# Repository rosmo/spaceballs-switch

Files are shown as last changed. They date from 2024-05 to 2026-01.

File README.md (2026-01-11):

# Spaceballs - The Switch!

Convert the [Concord Aerospace](https://www.concordaerospace.com/)'s 
[Ludicrous Speed Panel](https://www.concordaerospace.com/products/ludicrous-speed-control-panel) 
into a 5 switch Zigbee on/off switch. Only tested with Home Assistant. Switches 1-4 will be turned
on when the potentiometer is rotated (you may need to input your own calibration values though),
eg. plaid will have switched 1-4 in ON state. GO switch is switch number 5 and operates independently.

Requires ESP32-C6 and ESP-IDF 5.2. Tested with WeAct Studio ESP32-C6-MINI.

## Connecting hardware

Connect POT 1 to 3.3 VCC, POT 2 to pin 5, POT 3 to GND. Connect GO button to GND
and pin 20. Additional switch goes to pin 21 (and GND). Optional reset switch is at pin 17.

If you want to change the behavior so switches 1-4 are toggled independently, uncomment
`#define INDEPENDENT_SWITCHES`.

## Resetting device

Jumper 3V3 to pin 23 and reset the device.

## Building and flashing

Plug in your ESP32C6 to your computer (press BOOT, hold it and press RESET, then release BOOT) and replace `com4` with the
COM port the device appears on your computer.

1. `idf.py -p com4 erase-flash` 
2. `idf.py menuconfig`
3. `idf.py -p com4 flash`
4. Get the MAC address from console (the other port for ESP32-C6)
5. Create a manufacturing partition using [Zigbee Manufacturing Partition Generator Utility](https://github.com/espressif/esp-zigbee-sdk/blob/main/tools/mfg_tool/README.md).
6. Clone the zigbee sdk repo and remove the `from future.moves.itertools import zip_longest` from `tools/esp_zb_mfg_tool.py`.
7. Install dependencies in ESP-IDF shell: `python3 -m pip install -r requirements.txt` and `python3 -m pip install cryptography esp-idf-nvs-partition-gen crcmod`
8. Generate an installcode with Python: `python3 -c "import os;import crcmod.predefined;installcode=os.urandom(12);crc=crcmod.predefined.mkCrcFun('crc-16');print(installcode.hex() + hex(crc(installcode))[2:]);"`
9. Install dependencies for mgf tool: `python -m pip install esp_idf_nvs_partition_gen future`
10. Run: `python3 esp_zb_mfg_tool.py -i 7f91fbafb9ec53ee8097b3bb8fce -m 404ccafffe5627c4 -c 0x8000 -mn Espressif -mc 0x1338` (change first parameter to random string from previous command, second is MAC without colons)
11. Flash the binary to the `zb_fct` partition (at `0xf5000`): `esptool.py -p com4 write_flash 0xf5000 404ccafffe5627c4.bin`

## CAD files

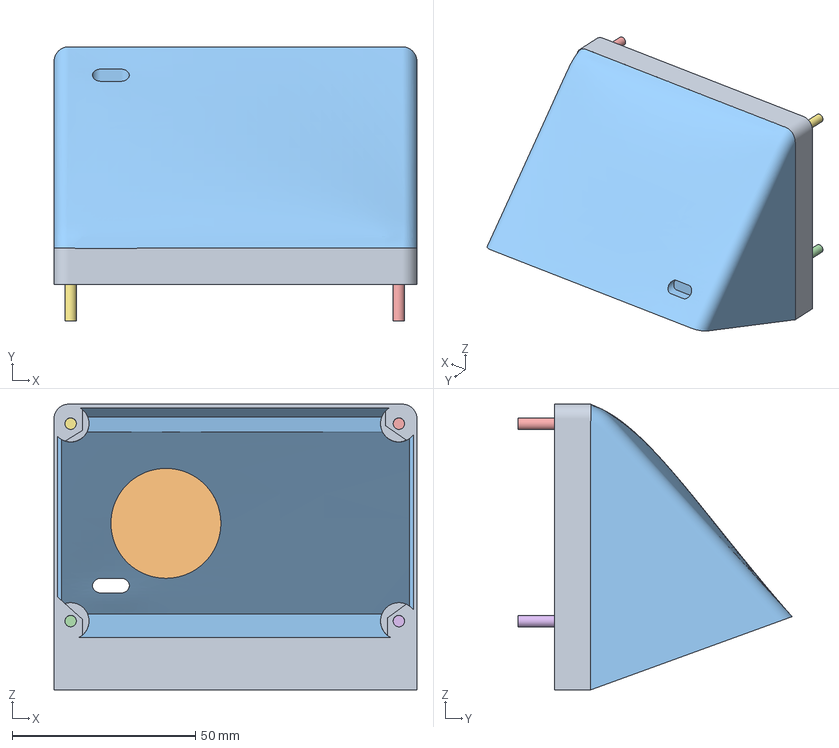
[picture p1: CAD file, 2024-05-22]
Spaceballs v6.3mf
99.1 x 74.9 x 78.0 mm
Front_plate
Pole
Wedge

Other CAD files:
Spaceballs v6.stl

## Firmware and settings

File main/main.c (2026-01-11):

#include "esp_check.h"
#include "esp_err.h"
#include "string.h"
#include "nvs_flash.h"
#include "esp_log.h"
#include "freertos/FreeRTOS.h"
#include "freertos/task.h"
#include "ha/esp_zigbee_ha_standard.h"
#include "main.h"
#include "esp_ieee802154.h"
#include "esp_mac.h"
#include "esp_adc/adc_oneshot.h"
#include "driver/gpio.h"

static const char *TAG = "ESP_ZB_SPACEBALLS";

// Spaceballs - The Switch!
static char modelid[] = {24, 'S', 'p', 'a', 'c', 'e', 'b', 'a', 'l', 'l', 's', ' ', '-', ' ', 'T', 'h', 'e', ' ', 'S', 'w', 'i', 't', 'c', 'h', '!'};
static char manufname[] = {9, 'E', 's', 'p', 'r', 'e', 's', 's', 'i', 'f'};

#if CONFIG_SPACEBALLS_BUTTON_PULLUP
#define BUTTON_PRESSED 0
#else
#define BUTTON_PRESSED 1
#endif

#define BUTTON_DEBUG 1
#define ADC_DEBUG 1

#define RESET_GPIO_PIN CONFIG_SPACEBALLS_RESET_GPIO

#define SB_ADC_CHANNEL CONFIG_SPACEBALLS_POTENTIOMETER_ADC_CHANNEL
#define SB_ADC_ATTEN   ADC_ATTEN_DB_12

#if SPACEBALLS_INDEPENDENT_SWITCHES
#define INDEPENDENT_SWITCHES 
#endif

#define BUTTON_1        (1<<0) // Light
#define BUTTON_2        (1<<1) // Ridiculous
#define BUTTON_3        (1<<2) // Ludicrous
#define BUTTON_4        (1<<3) // Plaid
#define BUTTON_5        (1<<4) // Go
#define BUTTON_6        (1<<5) // Additional switch
#define BUTTON_GPIO_5   CONFIG_SPACEBALLS_GO_GPIO     // Go button GPIO

trigger_range trigger_ranges[] = {
    {
        //.min = 2600,
        //.max = 3200,
        .min = 400,
        .max = 800,
        .button = BUTTON_1, // Light
        .name = "Light",
    },
    {
        //.min = 2100,
        //.max = 2599,
        .min = 800,
        .max = 1200,
        .button = BUTTON_2, // Ridiculous
        .name = "Ridiculous",
    },
    {
        //.min = 1200,
        //.max = 2099,
        .min = 1000,
        .max = 1700, 
        .button = BUTTON_3, // Ludicrous
        .name = "Ludicrous",
    },
    {
        //.min = 0,
        //.max = 1199,
        .min = 1500,
        .max = 4095,
        .button = BUTTON_4, // Plaid
        .name = "Plaid",
    },
};

#if CONFIG_SPACEBALLS_ADDITIONAL_SWITCH
#define TOTAL_BUTTONS           ((sizeof(trigger_ranges) / sizeof(trigger_range)) + 2)
#define GO_BUTTON_NUM           TOTAL_BUTTONS - 2
#define ADDITIONAL_BUTTON_NUM   TOTAL_BUTTONS - 1
#else
#define TOTAL_BUTTONS   ((sizeof(trigger_ranges) / sizeof(trigger_range)) + 1)
#define GO_BUTTON_NUM           TOTAL_BUTTONS - 1
#endif

// Internal button state
static uint8_t button_state = 0, previous_state = 0;
static uint8_t button_attrs[TOTAL_BUTTONS];
static uint8_t button_attrs_previous[TOTAL_BUTTONS];
static bool zigbee_initialized = false;

static nvs_handle_t nvs;
static float_t adc_reading = 0;

static SemaphoreHandle_t update_sem;

esp_err_t load_min_max_values(nvs_handle_t handle) 
{
    char key[32] = { '\0' };
    esp_err_t err;
    int16_t val;

    for (int i = 0; i < TOTAL_BUTTONS; i++) {
        // min value
        snprintf(key, 32, "min_%d", i);
        err = nvs_get_i16(handle, key, &val);
        if (err != ESP_OK) {
            return err;
        }
        trigger_ranges[i].min = (int)val;

        // max value
        snprintf(key, 32, "max_%d", i);
        err = nvs_get_i16(handle, key, &val);
        if (err != ESP_OK) {
            return err;
        }
        trigger_ranges[i].max = (int)val;
    }
    return ESP_OK;
}

esp_err_t save_min_max_values(nvs_handle_t handle) 
{
    char key[32] = { '\0' };
    esp_err_t err;
    for (int i = 0; i < TOTAL_BUTTONS; i++) {
        // min value
        snprintf(key, 32, "min_%d", i);
        err = nvs_set_i16(handle, key, (int16_t)trigger_ranges[i].min);
        if (err != ESP_OK) {
            return err;
        }

        // max value
        snprintf(key, 32, "max_%d", i);
        err = nvs_set_i16(handle, key, (int16_t)trigger_ranges[i].max);
        if (err != ESP_OK) {
            return err;
        }
    }
    return ESP_OK;
}

// Send updates of attribute changes
static void send_reports(uint8_t force_report)
{
    // Report status of the switches
    // Technically attribute reporting should take care of this, but to minimize
    // latency, we're just sending the updates ourselves.
#if 0
    esp_zb_lock_acquire(portMAX_DELAY);
    for (int endpoint_id = 0; endpoint_id < TOTAL_BUTTONS; endpoint_id++) {
        if (zigbee_initialized && (force_report || button_attrs_previous[endpoint_id] != button_attrs[endpoint_id])) {
            esp_zb_zcl_report_attr_cmd_t report_attr_cmd;

            ESP_LOGI(TAG, "Reporting status change for endpoint ID %d\n", endpoint_id + 1);
            report_attr_cmd.address_mode = ESP_ZB_APS_ADDR_MODE_DST_ADDR_ENDP_NOT_PRESENT;
            report_attr_cmd.attributeID = ESP_ZB_ZCL_ATTR_ON_OFF_ON_OFF_ID;
            report_attr_cmd.direction = ESP_ZB_ZCL_CMD_DIRECTION_TO_SRV;
            report_attr_cmd.clusterID = ESP_ZB_ZCL_CLUSTER_ID_ON_OFF;
            report_attr_cmd.zcl_basic_cmd.src_endpoint = endpoint_id + 1;

            esp_zb_zcl_status_t state = esp_zb_zcl_report_attr_cmd_req(&report_attr_cmd);
            if (state != ESP_ZB_ZCL_STATUS_SUCCESS) {
                ESP_LOGE(TAG, "Failed to report on/off status for endpoint %d!", endpoint_id + 1);
            }
            vTaskDelay(pdMS_TO_TICKS(25));
        }
    }
    esp_zb_lock_release();
#endif
    for (int endpoint_id = 0; endpoint_id < TOTAL_BUTTONS; endpoint_id++) {
        button_attrs_previous[endpoint_id] = button_attrs[endpoint_id];
    }
}

// This function updates the state of the switches in the on/off clusters
static void on_off_state_handler(uint8_t button_state)
{
     if (xSemaphoreTake(update_sem, pdMS_TO_TICKS(250)) == pdFALSE) {
        ESP_LOGE(TAG, "Failed to claim semaphore...");
        return;
     }

    // Just wait until endpoints are initialized - probably not the best way
    // but I'm not sure which signal is the best
    ESP_LOGI(TAG, "Updating Zigbee cluster values, button state=%d, ADC=%f", button_state, adc_reading);
    for (int endpoint_id = 0; endpoint_id < TOTAL_BUTTONS; endpoint_id++) {
        // Handle go button
#if CONFIG_SPACEBALLS_ADDITIONAL_SWITCH
        if (endpoint_id == ADDITIONAL_BUTTON_NUM) {
            button_attrs[endpoint_id] = button_state & (1 << endpoint_id) ? 1 : 0;
            continue;
        }
#endif
        if (endpoint_id == GO_BUTTON_NUM) {
            button_attrs[endpoint_id] = button_state & (1 << endpoint_id) ? 1 : 0;
        } else {
            // Keep all previous buttons on for the pot
            if (button_state & (1 << endpoint_id)) {
#ifndef INDEPENDENT_SWITCHES
                for (int i = endpoint_id; i >= 0; i--) {
                    button_attrs[i] = 1;
                }
#else
                button_attrs[endpoint_id] = 1;
#endif
            } else {
                button_attrs[endpoint_id] = 0;
            }
        }
    }

    // Update endpoint on/off attributes
    if (zigbee_initialized) {
        esp_zb_lock_acquire(portMAX_DELAY);
        for (int endpoint_id = 0; endpoint_id < TOTAL_BUTTONS; endpoint_id++) {
            // ESP_LOGI(TAG, "Endpoint %d, on/off status: %d", endpoint_id + 1, button_attrs[endpoint_id]);
            if (button_attrs_previous[endpoint_id] != button_attrs[endpoint_id]) {
                esp_zb_zcl_status_t state = esp_zb_zcl_set_attribute_val(endpoint_id + 1,
                                                                        ESP_ZB_ZCL_CLUSTER_ID_ON_OFF,
                                                                        ESP_ZB_ZCL_CLUSTER_SERVER_ROLE,
                                                                        ESP_ZB_ZCL_ATTR_ON_OFF_ON_OFF_ID,
                                                                        &button_attrs[endpoint_id],
                                                                        false);

                if (state != ESP_ZB_ZCL_STATUS_SUCCESS) {
                    ESP_LOGE(TAG, "Failed to update on/off status for endpoint %d!", endpoint_id + 1);
                } else {
                    // ESP_LOGI(TAG, "Updated endpoint %d on/off value", endpoint_id + 1);
                }
            }
        }
        // Set ADC reading
        esp_zb_zcl_status_t state = esp_zb_zcl_set_attribute_val(1,
                                                                 ESP_ZB_ZCL_CLUSTER_ID_ANALOG_INPUT,
                                                                 ESP_ZB_ZCL_CLUSTER_SERVER_ROLE,
                                                                 ESP_ZB_ZCL_ATTR_ANALOG_INPUT_PRESENT_VALUE_ID,
                                                                 &adc_reading,
                                                                 false);

        if (state != ESP_ZB_ZCL_STATUS_SUCCESS) {
            ESP_LOGE(TAG, "Failed to update ADC reading!");
        } else {
            ESP_LOGI(TAG, "ADC reading set to: %f", adc_reading);
        }

        esp_zb_lock_release();
    } else {
        ESP_LOGW(TAG, "Zigbee not initialized...");
    }

    if (zigbee_initialized) {
        send_reports((uint8_t)false);
    }

    xSemaphoreGive(update_sem);
}

static void handle_button_state_change(uint8_t previous_state, uint8_t button_state)
{
    if (zigbee_initialized) {
        ESP_LOGI(TAG, "Scheduling attribute update...");
        esp_zb_scheduler_alarm((esp_zb_callback_t)on_off_state_handler, button_state, 50);
    }
}

// Handles the rotary potentiometer and the throw switch
static void esp_controls_task(void *pvParameters)
{
    adc_oneshot_unit_handle_t adc1_handle;
    adc_oneshot_unit_init_cfg_t init_config1 = {
        .unit_id = ADC_UNIT_1,
    };

    // Initialize button attributes to zero
    for (int endpoint_id = 0; endpoint_id < TOTAL_BUTTONS; endpoint_id++) {
        button_attrs[endpoint_id] = 0;
        button_attrs_previous[endpoint_id] = 0;
    }

    ESP_LOGI(TAG, "Initializing GO switch GPIO %d", BUTTON_GPIO_5);
    gpio_config_t io_conf = {};
    io_conf.intr_type = GPIO_INTR_DISABLE;
    io_conf.mode = GPIO_MODE_INPUT;
    io_conf.pin_bit_mask = (1ULL << BUTTON_GPIO_5);
#if CONFIG_SPACEBALLS_BUTTON_PULLUP
    io_conf.pull_down_en = 0;
    io_conf.pull_up_en = 1;
#else
    io_conf.pull_down_en = 1;
    io_conf.pull_up_en = 0;
#endif
    ESP_ERROR_CHECK(gpio_config(&io_conf));

    if (gpio_get_level(BUTTON_GPIO_5) == BUTTON_PRESSED) {
        button_state |= BUTTON_5;
        ESP_LOGI(TAG, "GO button is ON! (Button state %d)", button_state);
    } else {
        ESP_LOGI(TAG, "GO button is OFF");
    }

#if CONFIG_SPACEBALLS_ADDITIONAL_SWITCH
    ESP_LOGI(TAG, "Initializing additional switch GPIO %d", CONFIG_SPACEBALLS_ADDITIONAL_SWITCH_GPIO);
    gpio_config_t addt_io_conf = {};
    addt_io_conf.intr_type = GPIO_INTR_DISABLE;
    addt_io_conf.mode = GPIO_MODE_INPUT;
    addt_io_conf.pin_bit_mask = (1ULL << CONFIG_SPACEBALLS_ADDITIONAL_SWITCH_GPIO);
#if CONFIG_SPACEBALLS_BUTTON_PULLUP
    addt_io_conf.pull_down_en = 0;
    addt_io_conf.pull_up_en = 1;
#else
    addt_io_conf.pull_down_en = 1;
    addt_io_conf.pull_up_en = 0;
#endif
    ESP_ERROR_CHECK(gpio_config(&addt_io_conf));

    if (gpio_get_level(CONFIG_SPACEBALLS_ADDITIONAL_SWITCH_GPIO) == BUTTON_PRESSED) {
        button_state |= BUTTON_6;
        ESP_LOGI(TAG, "Additional button is ON! (Button state %d)", button_state);
    } else {
        ESP_LOGI(TAG, "Additional button is OFF");
    }
#endif

    ESP_LOGI(TAG, "Initializing ADC, bits=%d, channel=%d, atten=%d", ADC_BITWIDTH_DEFAULT, SB_ADC_CHANNEL, SB_ADC_ATTEN);
    ESP_ERROR_CHECK(adc_oneshot_new_unit(&init_config1, &adc1_handle));

    int gpio = 0;
    adc_oneshot_channel_to_io(ADC_UNIT_1, SB_ADC_CHANNEL, &gpio);
    ESP_LOGI(TAG, "Using ADC connected to GPIO %d", gpio);

    adc_oneshot_chan_cfg_t config = {
        .bitwidth = ADC_BITWIDTH_DEFAULT,
        .atten = SB_ADC_ATTEN,
    };

    ESP_ERROR_CHECK(adc_oneshot_config_channel(adc1_handle, SB_ADC_CHANNEL, &config));

    int data = 0;
    for (int i = 0; i < 5; i++) {
        int init_data = 0;
        ESP_ERROR_CHECK(adc_oneshot_read(adc1_handle, SB_ADC_CHANNEL, &init_data));
        data += init_data;
        vTaskDelay(pdMS_TO_TICKS(50));
    }
    data = data / 5;
    adc_reading = ((float_t)data)/10;
    for (int i = 0; i < sizeof(trigger_ranges) / sizeof(trigger_range); i++) {
        if (data >= trigger_ranges[i].min /* && data <= trigger_ranges[i].max*/) {
            button_state |= trigger_ranges[i].button;
        }
    }

    if (gpio_get_level(BUTTON_GPIO_5) == BUTTON_PRESSED) {
            button_state |= BUTTON_5;
    }

#if CONFIG_SPACEBALLS_ADDITIONAL_SWITCH
    if (gpio_get_level(CONFIG_SPACEBALLS_ADDITIONAL_SWITCH_GPIO) == BUTTON_PRESSED) {
        button_state |= BUTTON_6;
    }
#endif

    ESP_LOGI(TAG, "Initial button state is: %d", button_state);
    
    int loop = 0;
    while (1) {
        if (button_state != previous_state) {
#if BUTTON_DEBUG
            ESP_LOGI(TAG, "Button state changed to %d.", button_state);
#endif
            handle_button_state_change(previous_state, button_state);
        }
        previous_state = button_state;

        ESP_ERROR_CHECK(adc_oneshot_read(adc1_handle, SB_ADC_CHANNEL, &data));
        loop += 1;
        if (loop > 10) {
#if ADC_DEBUG
            ESP_LOGI(TAG, "ADC reading is: %d", data);
#endif
            loop = 0;
        }
        if (gpio_get_level(BUTTON_GPIO_5) == BUTTON_PRESSED) {
            if (!(button_state & BUTTON_5)) {
                ESP_LOGI(TAG, "GO button turned on! (GPIO %d)", BUTTON_GPIO_5);
            }
            button_state |= BUTTON_5;
        } else {
            if (button_state & BUTTON_5) {
                ESP_LOGI(TAG, "GO button turned off!");
            }
            button_state = button_state & ~(BUTTON_5);
        }

#if CONFIG_SPACEBALLS_ADDITIONAL_SWITCH
        if (gpio_get_level(CONFIG_SPACEBALLS_ADDITIONAL_SWITCH_GPIO) == BUTTON_PRESSED) {
            if (!(button_state & BUTTON_6)) {
                ESP_LOGI(TAG, "Additional button turned on! (GPIO %d)", CONFIG_SPACEBALLS_ADDITIONAL_SWITCH_GPIO);
            }
            button_state |= BUTTON_6;
        } else {
            if (button_state & BUTTON_6) {
                ESP_LOGI(TAG, "Additional button turned off!");
            }
            button_state = button_state & ~(BUTTON_6);
        }
#endif

        for (int i = 0; i < sizeof(trigger_ranges) / sizeof(trigger_range); i++) {
            if (data >= trigger_ranges[i].min && data <= trigger_ranges[i].max) {
                if (!(button_state & trigger_ranges[i].button)) {
#if BUTTON_DEBUG
                    ESP_LOGI(TAG, "Button %d turned on, data is: %d", i, data);
#endif
                }
                button_state |= trigger_ranges[i].button;
            } else {
                if (button_state & trigger_ranges[i].button) {
#if BUTTON_DEBUG
                    ESP_LOGI(TAG, "Button %d turned off, data is: %d", i, data);
#endif
                }
                button_state = button_state & ~(trigger_ranges[i].button);
            }
        }
        vTaskDelay(pdMS_TO_TICKS(100));
    }
}

static void bdb_start_top_level_commissioning_cb(uint8_t mode_mask)
{
    esp_err_t err;

    err = esp_zb_bdb_start_top_level_commissioning(mode_mask);
    if (err == ESP_OK) {
        ESP_LOGI(TAG, "Started top level commissioning.");
    } else {
        ESP_LOGE(TAG, "Failed to start top level commissioning: %s", esp_err_to_name(err));
    }
}

void esp_zb_app_signal_handler(esp_zb_app_signal_t *signal_struct)
{
    uint32_t *p_sg_p     = signal_struct->p_app_signal;
    esp_err_t err_status = signal_struct->esp_err_status;
    esp_zb_app_signal_type_t sig_type = *p_sg_p;
    esp_zb_zdo_signal_leave_params_t *leave_params = NULL;
    esp_zb_zdo_signal_device_annce_params_t *dev_annce_params = NULL;

    if (xSemaphoreTake(update_sem, pdMS_TO_TICKS(1000)) == pdFALSE) {
        ESP_LOGE(TAG, "Failed to claim semaphore in signal handler...");
        return;
    }

    switch (sig_type) {
    case ESP_ZB_BDB_SIGNAL_FINDING_AND_BINDING_TARGET_FINISHED:
        ESP_LOGI(TAG, "Zigbee: ESP_ZB_BDB_SIGNAL_FINDING_AND_BINDING_TARGET_FINISHED");
        break;
    case ESP_ZB_BDB_SIGNAL_FINDING_AND_BINDING_INITIATOR_FINISHED:
        ESP_LOGI(TAG, "ESP_ZB_BDB_SIGNAL_FINDING_AND_BINDING_INITIATOR_FINISHED");
        break;
    case ESP_ZB_BDB_SIGNAL_STEERING_CANCELLED:
        ESP_LOGI(TAG, "ESP_ZB_BDB_SIGNAL_STEERING_CANCELLED");
        break;
    case ESP_ZB_BDB_SIGNAL_FORMATION_CANCELLED:
        ESP_LOGI(TAG, "ESP_ZB_BDB_SIGNAL_FORMATION_CANCELLED");
        break;
    case ESP_ZB_BDB_SIGNAL_TC_REJOIN_DONE:
        ESP_LOGI(TAG, "ESP_ZB_BDB_SIGNAL_TC_REJOIN_DONE");
        break;
    case ESP_ZB_ZDO_SIGNAL_SKIP_STARTUP:
        ESP_LOGI(TAG, "Initialize Zigbee stack");
        esp_zb_bdb_start_top_level_commissioning(ESP_ZB_BDB_MODE_INITIALIZATION);
        break;
    case ESP_ZB_ZDO_SIGNAL_LEAVE:
        leave_params = (esp_zb_zdo_signal_leave_params_t *)esp_zb_app_signal_get_params(p_sg_p);
        if (leave_params->leave_type == ESP_ZB_NWK_LEAVE_TYPE_RESET) {
            ESP_LOGI(TAG, "Reset device");
        }
        break;
    case ESP_ZB_BDB_SIGNAL_DEVICE_FIRST_START:
    case ESP_ZB_BDB_SIGNAL_DEVICE_REBOOT:
        if (err_status != ESP_OK) {
            ESP_LOGW(TAG, "Stack %s failure with %s status, steering", esp_zb_zdo_signal_to_string(sig_type), esp_err_to_name(err_status));
            esp_zb_scheduler_alarm((esp_zb_callback_t)bdb_start_top_level_commissioning_cb, ESP_ZB_BDB_MODE_NETWORK_STEERING, 1000);
        } else {
            ESP_LOGI(TAG, "Device started up in %s factory-reset mode", esp_zb_bdb_is_factory_new() ? "" : "non");
            if (esp_zb_bdb_is_factory_new()) {
                ESP_LOGI(TAG, "Start network steering");
                esp_zb_bdb_start_top_level_commissioning(ESP_ZB_BDB_MODE_NETWORK_STEERING);
            } else {
                ESP_LOGI(TAG, "Device rebooted");
                zigbee_initialized = true;

                // Just send an update, in case coordinator is out of sync
                // esp_zb_scheduler_alarm((esp_zb_callback_t)send_reports, (uint8_t)true, 1000);
            }
        }
        break;
    case ESP_ZB_ZDO_SIGNAL_DEVICE_ANNCE:
        dev_annce_params = (esp_zb_zdo_signal_device_annce_params_t *)esp_zb_app_signal_get_params(p_sg_p);
        ESP_LOGI(TAG, "New device commissioned or rejoined (short: 0x%04hx)", dev_annce_params->device_short_addr);
        break;
    case ESP_ZB_BDB_SIGNAL_STEERING:
    case ESP_ZB_BDB_SIGNAL_FORMATION:
        if (err_status == ESP_OK) {
            esp_zb_ieee_addr_t extended_pan_id;
            esp_zb_get_extended_pan_id(extended_pan_id);
            ESP_LOGI(TAG, "Joined network successfully (Extended PAN ID: %02x:%02x:%02x:%02x:%02x:%02x:%02x:%02x, PAN ID: 0x%04hx, Channel:%d, Short Address: 0x%04hx)",
                     extended_pan_id[7], extended_pan_id[6], extended_pan_id[5], extended_pan_id[4],
                     extended_pan_id[3], extended_pan_id[2], extended_pan_id[1], extended_pan_id[0],
                     esp_zb_get_pan_id(), esp_zb_get_current_channel(), esp_zb_get_short_address());
            zigbee_initialized = true;
            esp_zb_scheduler_alarm((esp_zb_callback_t)send_reports, (uint8_t)true, 1000);
        } else {
            ESP_LOGI(TAG, "Network steering was not successful (status: %s)", esp_err_to_name(err_status));
            esp_zb_scheduler_alarm((esp_zb_callback_t)bdb_start_top_level_commissioning_cb, ESP_ZB_BDB_MODE_NETWORK_STEERING, 1000);
        }
        break;
    case ESP_ZB_NWK_SIGNAL_PERMIT_JOIN_STATUS:
        if (err_status == ESP_OK) {
            if (*(uint8_t *)esp_zb_app_signal_get_params(p_sg_p)) {
                ESP_LOGI(TAG, "Network(0x%04hx) is open for %d seconds", esp_zb_get_pan_id(), *(uint8_t *)esp_zb_app_signal_get_params(p_sg_p));
            } else {
                ESP_LOGW(TAG, "Network(0x%04hx) closed, devices joining not allowed.", esp_zb_get_pan_id());
            }
        }
        break;
    case ESP_ZB_NLME_STATUS_INDICATION:
        if (err_status == ESP_OK) {
            zigbee_initialized = true;
        } else {
            ESP_LOGE(TAG, "ZDO signal: %s (0x%x), status: %s", esp_zb_zdo_signal_to_string(sig_type), sig_type, esp_err_to_name(err_status));

        }
        break;
    default:
        ESP_LOGI(TAG, "ZDO signal: %s (0x%x), status: %s", esp_zb_zdo_signal_to_string(sig_type), sig_type, esp_err_to_name(err_status));
        break;
    }
    xSemaphoreGive(update_sem);
}

static esp_err_t zb_attribute_reporting_handler(const esp_zb_zcl_report_attr_message_t *message)
{
    return ESP_OK;
}
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
void app_main(void)
{
    esp_err_t err;
    esp_zb_platform_config_t config = {
        .radio_config = ESP_ZB_DEFAULT_RADIO_CONFIG(),
        .host_config = ESP_ZB_DEFAULT_HOST_CONFIG(),
    };

    uint8_t ieeeMac[8] = { 0 };
    esp_read_mac(ieeeMac, ESP_MAC_IEEE802154);
    ESP_LOGI(TAG, "Zigbee MAC: %02x:%02x:%02x:%02x:%02x:%02x:%02x:%02x", ieeeMac[0], ieeeMac[1], ieeeMac[2], ieeeMac[3], ieeeMac[4], ieeeMac[5], ieeeMac[6], ieeeMac[7]);

    ESP_LOGI(TAG, "nvs_flash_init()");
    err = nvs_flash_init();
    if (err == ESP_ERR_NVS_NO_FREE_PAGES || err == ESP_ERR_NVS_NEW_VERSION_FOUND) {
      ESP_ERROR_CHECK(nvs_flash_erase());
      err = nvs_flash_init();
    }
    ESP_ERROR_CHECK(err);

    err = nvs_open("storage", NVS_READWRITE, &nvs);
    ESP_ERROR_CHECK(err);

    ESP_LOGI(TAG, "Loading ADC values from NVS...");
    err = load_min_max_values(nvs);
    if (err != ESP_OK) {
        ESP_LOGI(TAG, "No values in NVS, storing default values.");
        ESP_ERROR_CHECK(save_min_max_values(nvs));
    }

    ESP_ERROR_CHECK(esp_zb_platform_config(&config));
    update_sem = xSemaphoreCreateMutex();
    assert(update_sem != NULL);

    xTaskCreate(esp_zb_task, "Zigbee_main", 4096, NULL, 5, NULL);
    xTaskCreate(esp_controls_task, "Controls", 4096, NULL, 5, NULL);
}

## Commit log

2024-05-06 Add support for independent switches.
2024-05-22 Add 3D models
    [Spaceballs v6.3mf, Spaceballs v6.stl]
2024-09-21 Add support for Fortunate Son button (or any other additional button via configurable GPIO)
2024-09-29 Make it more configurable and fix additional switch
    [main.c]
2026-01-11 Add configurable ADC limits, update to ESP-IDF 5.3 and latest Zigbee libraries. Remove notification mechanism.
